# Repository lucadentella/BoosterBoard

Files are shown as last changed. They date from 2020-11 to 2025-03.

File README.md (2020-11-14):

# BoosterBoard
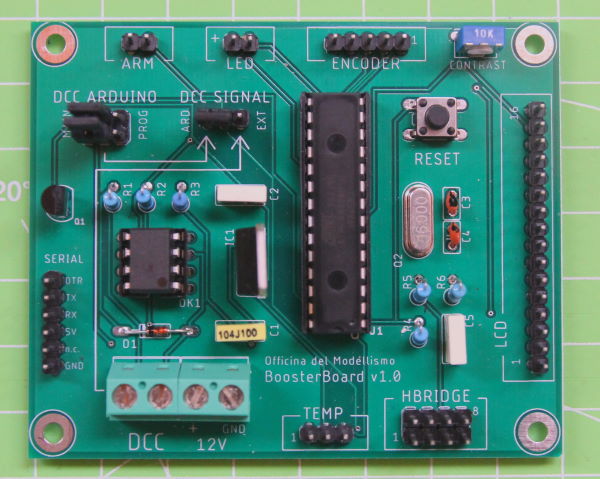
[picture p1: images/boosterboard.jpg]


BoosterBoard is an opensource board to create a powerful DCC Booster or Command Station.

*BoosterBoard è una scheda opensource disegnata per realizzare un potente Booster DCC o una completa Centralina Digitale.*

## Documentation
 - [Youtube video](https://www.youtube.com/watch?v=jXaGD2t4H4I)
 - [Assembly instructions (*english*)](https://github.com/lucadentella/BoosterBoard/blob/main/documentation/assembly-en.md)
 - [Guide for use as a DCC Booster (*english*)](https://github.com/lucadentella/BoosterBoard/blob/main/documentation/booster-en.md)
 - [Guide for use as a DCC Command Station (*english*)](https://github.com/lucadentella/BoosterBoard/blob/main/documentation/commandstation-en.md)
 
## Documentazione
 - [Video su Youtube](https://www.youtube.com/watch?v=6GtECbDPArw)
 - [Istruzioni per il montaggio (*italiano*)](https://github.com/lucadentella/BoosterBoard/blob/main/documentation/assembly-it.md)
 - [Guida per l'utilizzo come Booster DCC (*italiano*)](https://github.com/lucadentella/BoosterBoard/blob/main/documentation/booster-it.md)
 - [Guida per l'utilizzo come Centralina DCC (*italiano*)](https://github.com/lucadentella/BoosterBoard/blob/main/documentation/commandstation-it.md)

## Technical documents / *Documenti tecnici*
 - [Schematics / *Schema elettrico* (pdf)](https://github.com/lucadentella/BoosterBoard/blob/main/board/BoosterBoard.pdf)
 - [Eagle files](https://github.com/lucadentella/BoosterBoard/tree/main/board)
 - [Part list / *Elenco componenti*](https://github.com/lucadentella/BoosterBoard/blob/main/documentation/partlist.md)

## PCB
PCBs can be ordered directly from PCBWay
*I PCB possono essere ordinati direttamente da PCBWay* 
https://www.pcbway.com/project/shareproject/BoosterBoard.html

## References / *Riferimenti*
 - [A High Power DCC Booster](http://www.trainelectronics.com/DCC_Arduino/DCC_Booster/) (D. Bodnar)
 - [DCC++ BaseStation](https://github.com/DccPlusPlus/BaseStation)

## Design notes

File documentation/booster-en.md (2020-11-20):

# BoosterBoard as DCC Booster

## Firmware

Connect a USB to Serial adapter to the `SERIAL` port as follows:

> It's important to connect `DTR` pin to automatically reset the microcontroller during programing and to **swap** `RX` and `TX` pins

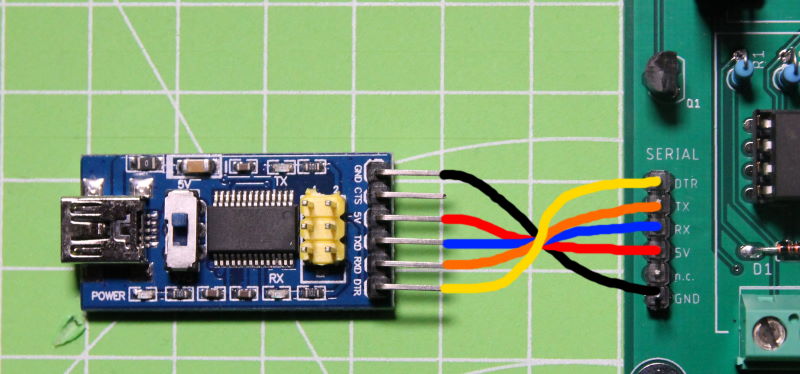
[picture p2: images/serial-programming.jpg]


Download the [latest firmware](https://github.com/lucadentella/BoosterBoard/tree/main/firmware) from Github and program using Arduino IDE (select *Arduino Uno* as board).

## Jumpers

Insert the jumpers as follows:

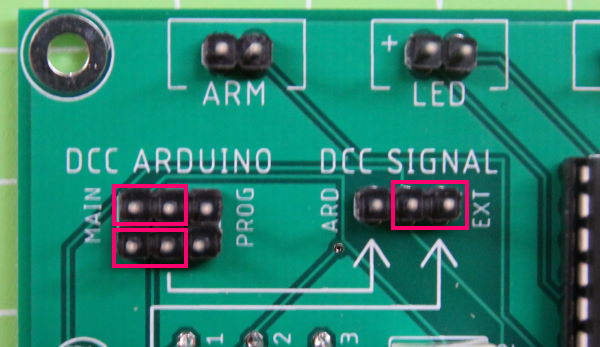
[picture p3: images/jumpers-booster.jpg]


## Connections

Connect LED, button and encoder as follows:

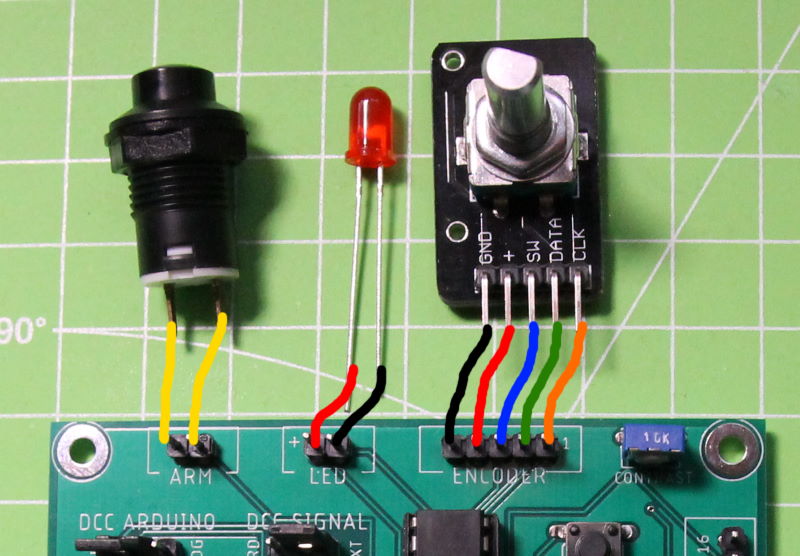
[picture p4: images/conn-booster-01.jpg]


Connect the display to the corresponding port (`LCD`), **pin to pin** (1->1, 2->2...): 

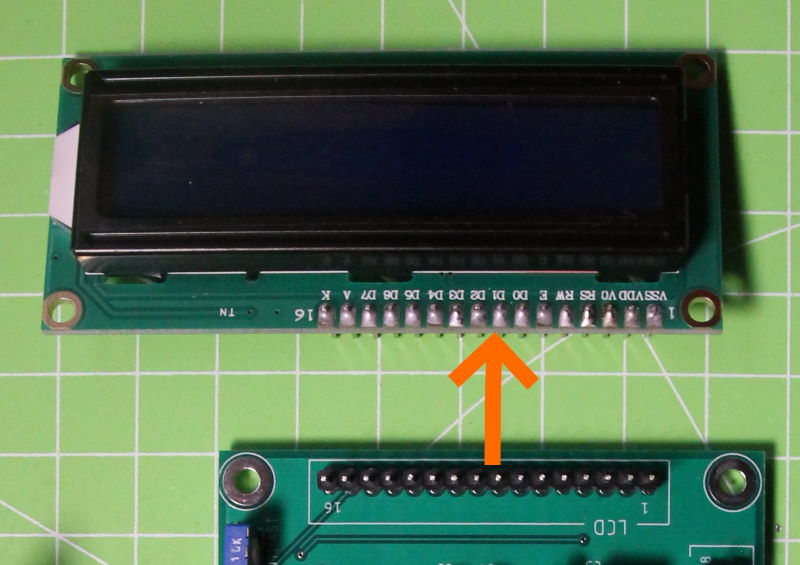
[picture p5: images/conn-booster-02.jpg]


Connect the H-Bridge board to `H-BRIDGE` port (1->1, 2->2...) and the temperature sensor as follows:

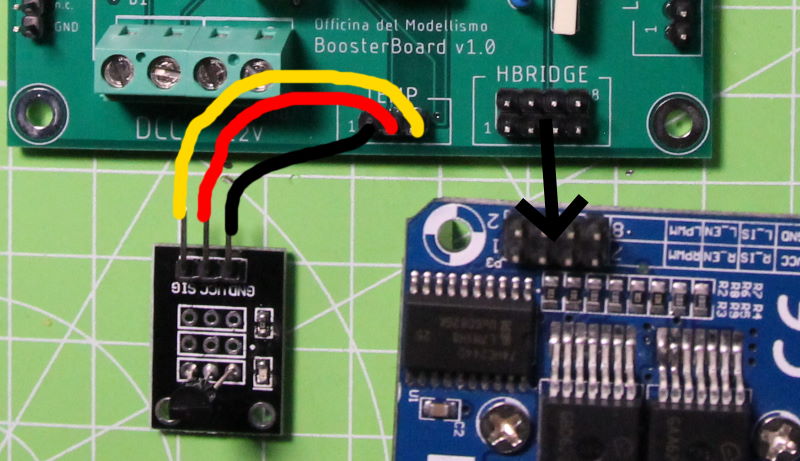
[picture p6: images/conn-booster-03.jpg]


## Operation

Power BoosterBoard connecting **12V and GND**. Connect the **DCC** input signal to the `DCC` terminal block.

Power the H bridge (`B+ B-` terminals) and connect the output (`M+ M-` terminals) to the layout:

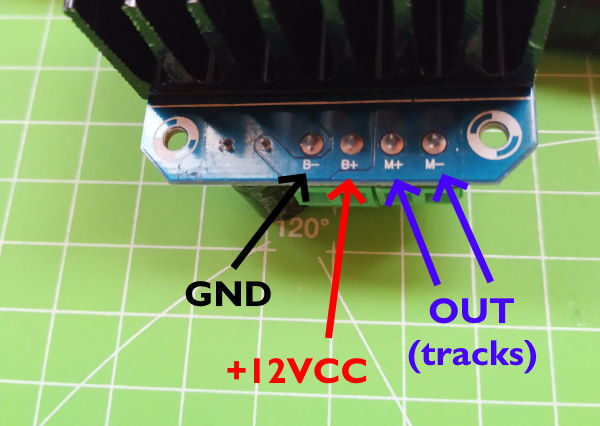
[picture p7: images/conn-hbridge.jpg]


BoosterBoard starts in **STOP** mode. You can turn the booster ON and OFF pressing the push button.

When the booster is OFF, you can change the maximum current and temperature using the rotary encoder.

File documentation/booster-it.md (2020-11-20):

# BoosterBoard come DCC Booster

## Firmware

Colleghiamo un adattatore USB Seriale alla porta `SERIAL` come segue:

> E' importante collegare il pin `DTR` per il reset automatico del microcontrollore durante la programmazione  e **invertire** i pin `RX` e `TX`



Scarichiamo [l'ultima versione del firmware](https://github.com/lucadentella/BoosterBoard/tree/main/firmware) da Github e programmiamo la scheda usando l'IDE di Arduino (selezioniamo *Arduino Uno* come scheda).

## Jumpers

Inseriamo i jumpers nelle posizioni evidenziate:



## Collegamenti

Colleghiamo il LED, il pulsante e l'encoder come segue:



Colleghiamo il display alla porta corrispondente (`LCD`), **pin to pin** (1->1, 2->2...): 



Colleghiamo il ponte H alla porta `H-BRIDGE` (1->1, 2->2...) e il sensore temperatura come segue:



## Funzionamento

Alimentiamo BoosterBoard collegando **12V e massa**. Colleghiamo il segnale **DCC** alla morsettiera `DCC`.

Alimentiamo il ponte H (morsettiera `B+ B-`) e colleghiamo la sua uscita (morsettiera `M+ M-`) al tracciato:



BoosterBoard si avvia in modalità **STOP**. E' possibile ACCENDERE e SPEGNERE il booster premendo il pulsante.

Quando il booster è SPENTO, è possibile modificare i valori massimi di corrente e temperatura usando l'encoder.

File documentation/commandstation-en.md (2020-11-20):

# BoosterBoard as DCC Command Station

## Firmware

Connect a USB to Serial adapter to the `SERIAL` port as follows:

> It's important to connect `DTR` pin to automatically reset the microcontroller during programing and to **swap** `RX` and `TX` pins



BoosterBoard is compatible with [DCC++ Base Station](https://github.com/DccPlusPlus/BaseStation). 

Download the latest version of this firmware from Github and program using Arduino IDE (select *Arduino Uno* as board).

## Jumpers

Insert the jumpers as follows:

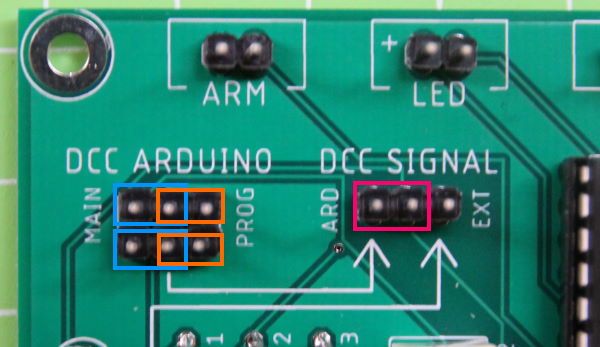
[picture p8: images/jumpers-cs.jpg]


Having only one H-Bridge, you have to choose which DCC++ signal will be its input.

Use the **blue** position for the `MAIN TRACK` signal or the **orange** position for the `PROGRAMMING TRACK` one.

## Connections

DCC++ doesn't support external peripherals like displays or buttons. 

You only need to connect a USB to Serial adapter to send commands to the command station from your computer. Connect the adapter as follows:

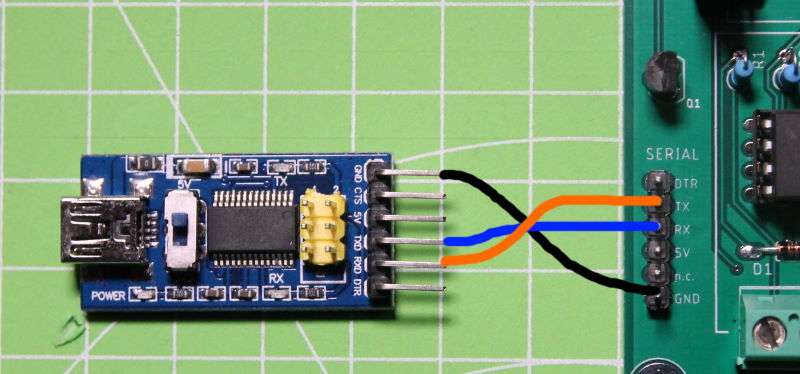
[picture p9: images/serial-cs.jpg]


## Operation

Power BoosterBoard connecting **12V and GND**.

Power the H bridge (`B+ B-` terminals) and connect the output (`M+ M-` terminals) to the layout:



Connect the Serial adapter to your computer.

Use a software which supports DCC++ to send commands to the command station and control your layout.

Some free programs I tested:

 - JMRI (https://www.jmri.org/)
 - Rocrail (https://wiki.rocrail.net/doku.php)

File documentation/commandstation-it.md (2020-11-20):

# BoosterBoard come Centralina DCC

## Firmware

Colleghiamo un adattatore USB Seriale alla porta `SERIAL` come segue:

> E' importante collegare il pin `DTR` per il reset automatico del microcontrollore durante la programmazione  e **invertire** i pin `RX` e `TX`



BoosterBoard è compatibile con [DCC++ Base Station](https://github.com/DccPlusPlus/BaseStation). 

Scarichiamo l'ultima versione del firmware da Github e programmiamo la scheda usando l'IDE di Arduino (selezioniamo *Arduino Uno* come scheda).

## Jumpers

Inseriamo i jumpers nelle posizioni evidenziate:



Avendo solo un ponte H, dobbiamo scegliere quale segnale DCC++ inviare al suo ingresso.

Usiamo le posizioni in **blu** per il `TRACCIATO PRINCIPALE (MAIN`) o le posizioni in **arancione** per il `BINARIO DI PROGRAMMAZIONE`.

## Collegamenti

DCC++ non supporta periferiche esterne come display o pulsanti. 

Dobbiamo solo collegare un adattatore USB Seriale per inviare comandi alla command station dal nostro computer. Colleghiamo l'adattatore come segue:



## Funzionamento

Alimentiamo BoosterBoard collegando **12V e massa**.

Alimentiamo il ponte H (morsettiera `B+ B-`) e colleghiamo la sua uscita (morsettiera `M+ M-`) al tracciato:



Colleghiamo l'adattatore seriale al nostro computer.

Utilizziamo un programma che supporti DCC++ per inviare comandi alla centralina e controllare il plastico.

Alcuni programmi gratuiti che ho testato:

 - JMRI (https://www.jmri.org/)
 - Rocrail (https://wiki.rocrail.net/doku.php)

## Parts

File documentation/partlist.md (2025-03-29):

# Part list / *Elenco componenti*
## For the board / Per la scheda
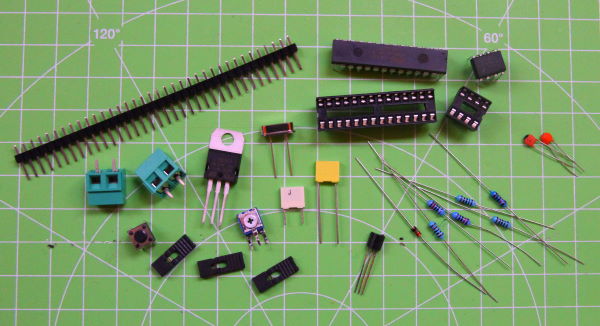
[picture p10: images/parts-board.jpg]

|Name|Description|Value
|--|--|--|
|R1,R6|Resistor 1/4W 1%|1Kohm|
|R2,R3,R4,R5|Resistor 1/4W 1%|10Kohm|
|R7|Variable resistor (RM063)|10Kohm|
|C1|Ceramic capacitor|330nF|
|C2,C5|Ceramic capacitor|100nF|
|C3,C4|Ceramic capacitor|22pF|
|D1|Diode|1N4148|
|Q1|Mosfet|2N7000|
|Q2|Crystal|16MHz|
|U1|Microcontroller|ATmega328p|
|OK1|Optocoupler|6N137|
|IC1|Voltage regulator|L7805|
|RESET_SW|Tactile switch|Omron|
|12VCC,DCC|Terminal block|2P 5mm|
|JMPs|Jumpers|
|ARM,DCC_IN,DCC_OUT...|Pin headers|
## To use as a DCC Booster / Per l'utilizzo come Booster DCC
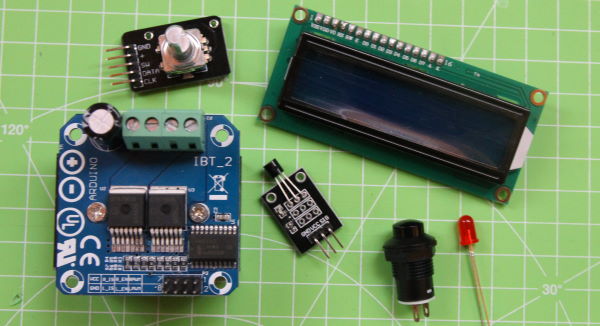
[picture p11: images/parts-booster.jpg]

> Links are for reference only, similar products will work well too / *I link sono forniti solo come riferimento, prodotti simili funzioneranno egualmente bene*

|Name|Description|Link
|--|--|--|
|HBRIDGE|BTS7960B motor driver / *Driver motori BTS7960B*|https://www.aliexpress.com/w/wholesale-double-BTS7960B.html|
|ARM|Momentary push button / *Pulsante da pannello*|https://bit.ly/2Idf11M|
|LED|LED, choose the color you prefer / *LED, scegli il colore che preferisci*|
|ENCODER|EC11 Rotary encoder / *Encoder rotativo*|https://www.aliexpress.com/w/wholesale-ec11-rotary-encoder.html
|LCD|16x2 character display / *Display a caratteri 16x2*|https://www.aliexpress.com/w/wholesale-lcd-16x2.html
|TEMP|DS18B20 temperature sensor / *Sensore temperatura DS18B20*|https://www.aliexpress.com/w/wholesale-DS18B20-module-single.html
## To use as a DCC Command Station / Per l'utilizzo come Centralina DCC
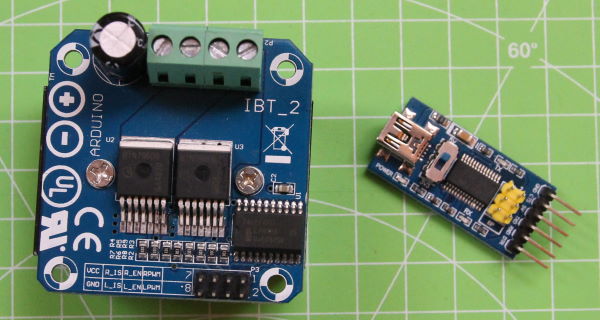
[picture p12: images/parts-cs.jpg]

|Name|Description|Link
|--|--|--|
|HBRIDGE|BTS7960B motor driver / *Driver motori BTS7960B*|https://www.aliexpress.com/w/wholesale-double-BTS7960B.html|
|SERIAL|USB to serial adapter / *Modulo USB - seriale*|https://www.aliexpress.com/w/wholesale-usb-serial-adapter.html

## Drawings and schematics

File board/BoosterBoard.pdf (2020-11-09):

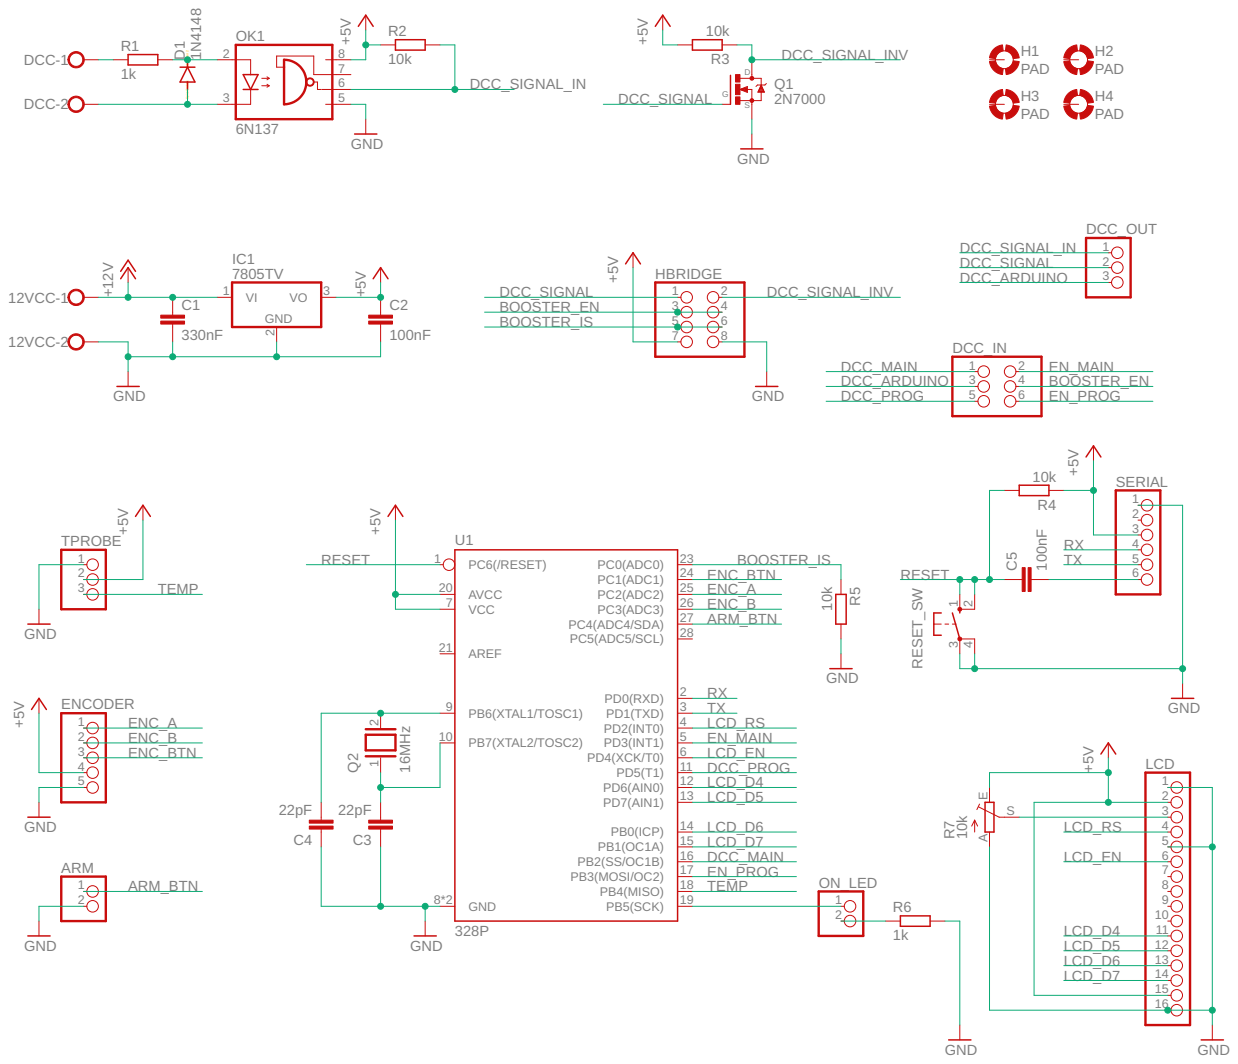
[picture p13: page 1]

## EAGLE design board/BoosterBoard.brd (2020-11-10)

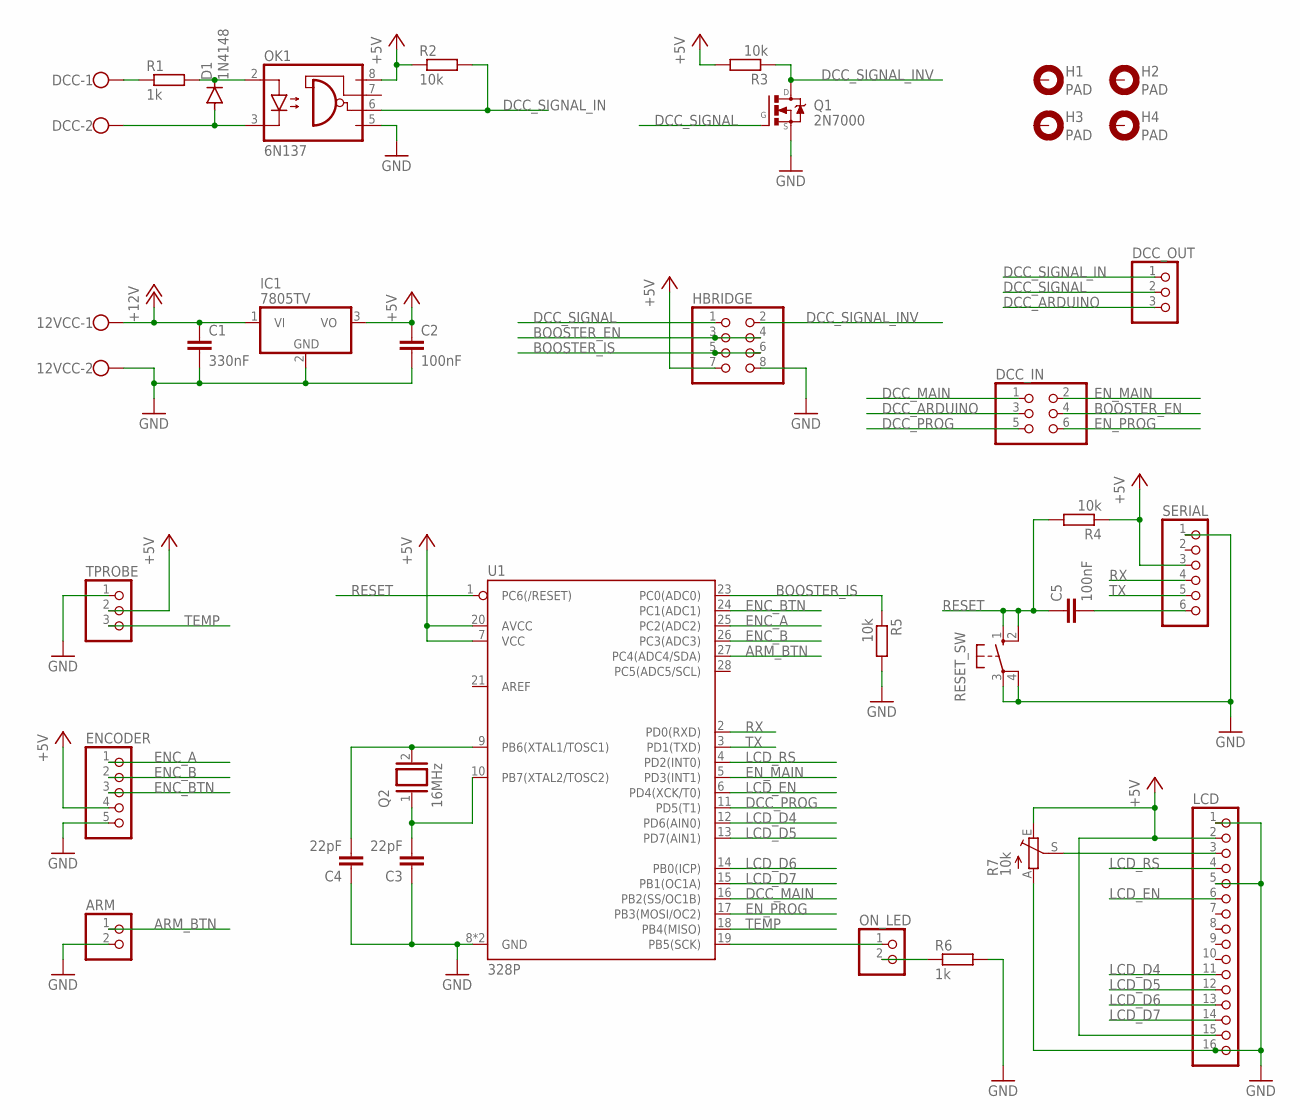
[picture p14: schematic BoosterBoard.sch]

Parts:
12VCC: W237-102
ARM: PINHD-1X2; 1X02
C1: 330nF; C050-030X075
C2, C5: 100nF; C050-030X075
C3, C4: 22pF; C025-025X050
D1: 1N4148; DO35-10
DCC: W237-102
DCC_IN: PINHD-2X3; 2X03
DCC_OUT: PINHD-1X3; 1X03
ENCODER: PINHD-1X5; 1X05
H1, H2, H3, H4: PAD; 3,0-PAD
HBRIDGE: PINHD-2X4; 2X04
IC1: 7805TV; TO220V
LCD: PINHD-1X16; 1X16
OK1: 6N137; DIL08
ON_LED: PINHD-1X2; 1X02
Q1: 2N7000; TO-92
Q2: 16MHz; QS
R1, R6: 1k; 0207/2V
R2, R3, R4, R5: 10k; 0207/2V
R7: 10k; B64W
RESET_SW: 10-XX; B3F-10XX
SERIAL: PINHD-1X6; 1X06
TPROBE: PINHD-1X3; 1X03
U1: 328P; DIP28

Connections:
+5V: C2.1, ENCODER.4, HBRIDGE.7, IC1.3 (VO), LCD.2, LCD.15, OK1.8 (VCC), R2.1, R3.2, R4.1, R7.E, SERIAL.3, TPROBE.2, U1.7 (VCC), U1.20 (AVCC)
+12V: 12VCC.1, C1.1, IC1.1 (VI)
ARM_BTN: ARM.1, U1.27 (PC4(ADC4/SDA))
BOOSTER_EN: DCC_IN.4, HBRIDGE.3, HBRIDGE.4
BOOSTER_IS: HBRIDGE.5, HBRIDGE.6, R5.1, U1.23 (PC0(ADC0))
DCC_ARDUINO: DCC_IN.3, DCC_OUT.3
DCC_MAIN: DCC_IN.1, U1.16 (PB2(SS/OC1B))
DCC_PROG: DCC_IN.5, U1.11 (PD5(T1))
DCC_SIGNAL: DCC_OUT.2, HBRIDGE.1, Q1.2 (G)
DCC_SIGNAL_IN: DCC_OUT.1, OK1.6 (VO), R2.2
DCC_SIGNAL_INV: HBRIDGE.2, Q1.3 (D), R3.1
ENC_A: ENCODER.1, U1.25 (PC2(ADC2))
ENC_B: ENCODER.2, U1.26 (PC3(ADC3))
ENC_BTN: ENCODER.3, U1.24 (PC1(ADC1))
EN_MAIN: DCC_IN.2, U1.5 (PD3(INT1))
EN_PROG: DCC_IN.6, U1.17 (PB3(MOSI/OC2))
GND: 12VCC.2, ARM.2, C1.2, C2.2, C3.1, C4.1, ENCODER.5, HBRIDGE.8, IC1.2 (GND), LCD.1, LCD.5, LCD.16, OK1.5 (GND), Q1.1 (S), R5.2, R6.2, R7.A, RESET_SW.3, RESET_SW.4 (P1), SERIAL.1, TPROBE.1, U1.8 (GND), U1.22 (GND)
LCD_D4: LCD.11, U1.12 (PD6(AIN0))
LCD_D5: LCD.12, U1.13 (PD7(AIN1))
LCD_D6: LCD.13, U1.14 (PB0(ICP))
LCD_D7: LCD.14, U1.15 (PB1(OC1A))
LCD_EN: LCD.6, U1.6 (PD4(XCK/T0))
LCD_RS: LCD.4, U1.4 (PD2(INT0))
unnamed: DCC.1, R1.1
unnamed: D1.C, OK1.2 (A), R1.2
unnamed: D1.A, DCC.2, OK1.3 (C)
unnamed: C4.2, Q2.2, U1.9 (PB6(XTAL1/TOSC1))
unnamed: C3.2, Q2.1, U1.10 (PB7(XTAL2/TOSC2))
unnamed: C5.2, SERIAL.6
unnamed: ON_LED.1, U1.19 (PB5(SCK))
unnamed: ON_LED.2, R6.1
unnamed: LCD.3, R7.S
RESET: C5.1, R4.2, RESET_SW.1 (S), RESET_SW.2 (S1), U1.1 (PC6(/RESET))
RX: SERIAL.4, U1.2 (PD0(RXD))
TEMP: TPROBE.3, U1.18 (PB4(MISO))
TX: SERIAL.5, U1.3 (PD1(TXD))

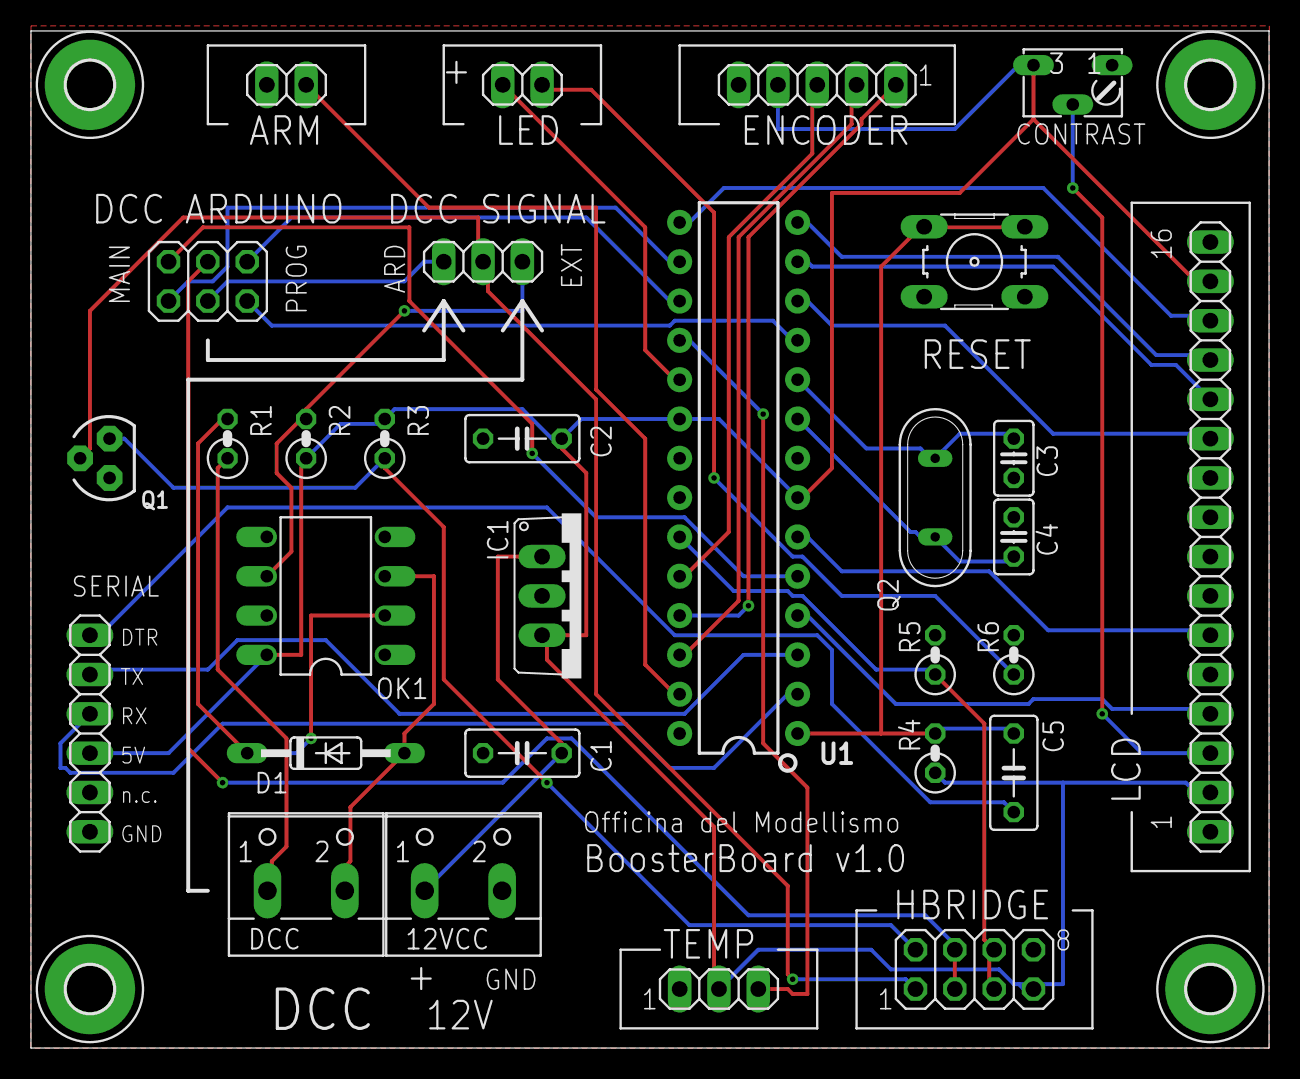
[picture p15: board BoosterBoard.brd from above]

Board: 2 copper layers, 80.0 x 65.7 mm, 34 parts (0 on the bottom side), 36 nets.

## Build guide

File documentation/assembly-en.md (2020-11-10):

# Assembly instructions
Start soldering the lowest components (diode, crystal, 22pf capacitors). I strongly suggest the use of **sockets** for ICs:

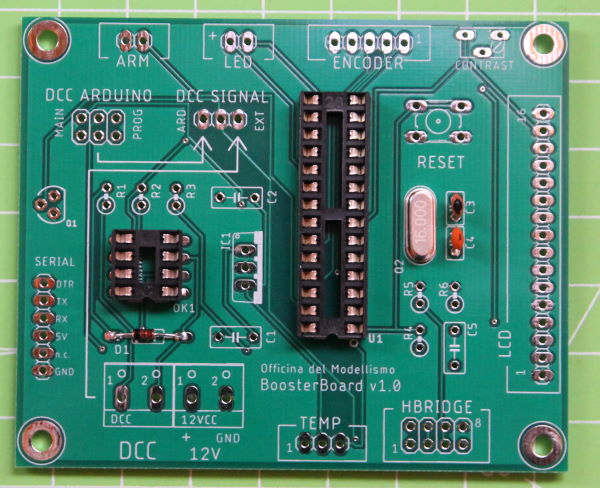
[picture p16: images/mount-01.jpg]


Continue with the remaining capacitors and the the transistor:

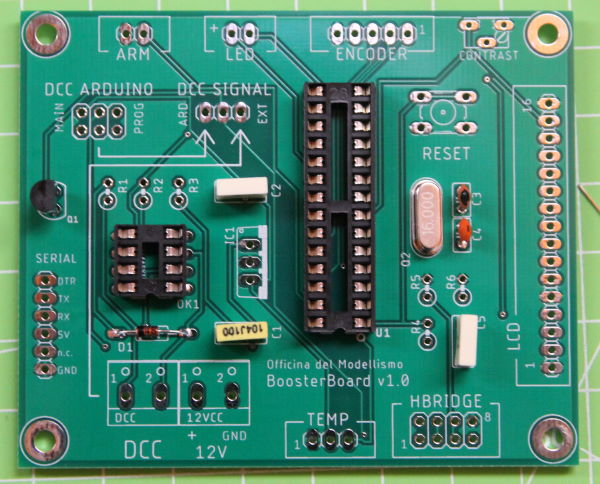
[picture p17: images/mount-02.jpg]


It's now time to solder the resistors (including the variable one), the pin headers and the switch:

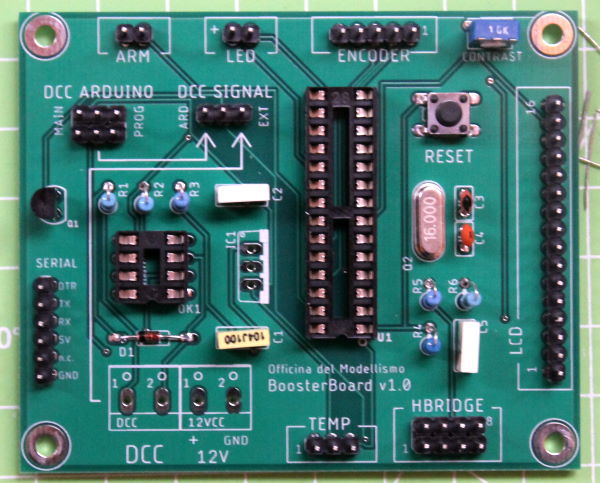
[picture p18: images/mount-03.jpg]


Complete the board with the terminal blocks and the voltage regulator:

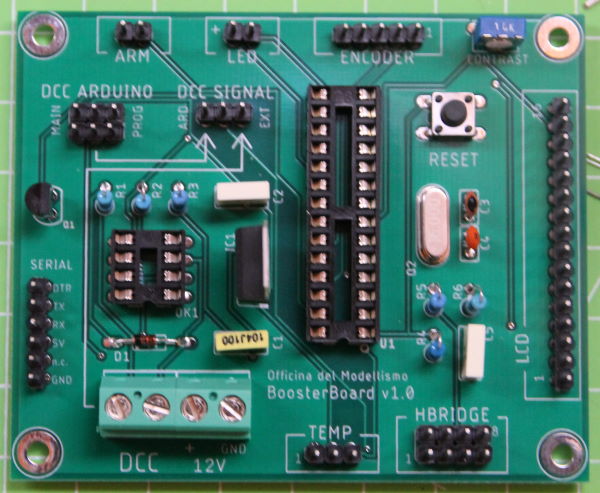
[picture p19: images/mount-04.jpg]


If you chose to use sockets, now you can insert the ICs. 
ATmega328p must be programmed with **Arduino bootloader**. You can buy pre-programmed microcontrollers or burn the bootloader using one Arduino Uno running the *ArduinoISP* firmware:



I found very useful [this shield](https://bit.ly/38shwaZ) to program the bootloader:

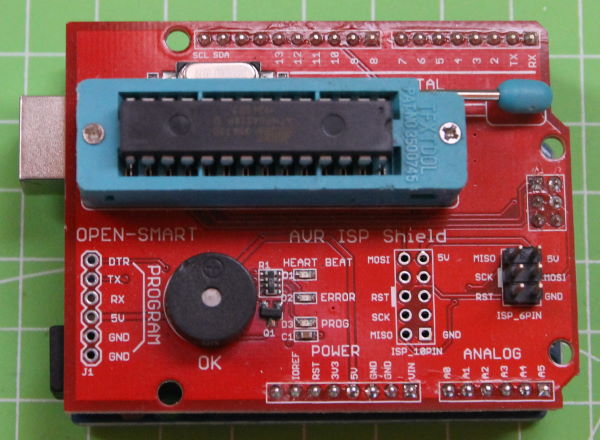
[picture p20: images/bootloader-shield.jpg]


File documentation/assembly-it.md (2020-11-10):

# Istruzioni per il montaggio
Iniziamo saldando i componenti più bassi (diodo, quarzo, condensatori da 22pf). Consiglio fortemente l'utilizzo di **sockets** per i circuiti integrati:



Continuiamo con i condensatori rimanenti e il transistor:



E' ora tempo di saldare le resistenze (inclusa quella variabile), i pin e il pulsante:



Completiamo la scheda con le morsettiere e il regolatore di tensione:



Se avete scelto di usare i sockets, è ora possibile inserire i circuiti stampati. 
L'atmega328p deve essere programmato con il **bootloader Arduino**. E' possibile acquistare microcontrollori già programmati o programmare il bootloader usando un Arduino Uno che esegue il firmware *ArduinoISP*:



Ho trovato molto utile [questo shield](https://bit.ly/38shwaZ) per programmare il bootloader:



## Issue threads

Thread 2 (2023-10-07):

Shortcircuit is to fast

Knitterpitti, 2023-10-07:
Hello Luca,
at first i will thank you for this great Project.

I have build the Boosterboard it runs fine with a DCC++ Arduino Central and Rocrail.
But i use two sweeping loop´s with DR 5013 Modules.
[https://www.manualslib.com/manual/1512127/Digikeijs-Dr5013-Digireverse.html#manual](url)
Now my Problem:
The Shortcircuit detection from the booster is faster then the Modules can switch the Polarisation.

Can you insert a delay witch stop the Booster after a half Second after the short circuit!
Not directly after detection!

My Central Station DR5000 is going to shortcircuit after 100 miliseconds this runs great with the sweeping loop´s.

Thank you for your Time,

Greatings Sebastian Kuhnert (Knitterpitti)

lucadentella, 2023-10-09:
Hi Sebastian

I'm not going to change the normal behavior of the booster because it's important to detect a short circuit as soon as it happens.

Anyway I'm aware that some loop modules do require some ms to activate.
You can alter the code that detects short circuits, starting from line:

https://github.com/lucadentella/BoosterBoard/blob/06c8bd1694cb7f5fff553e723a42c103eaa35553/firmware/BoosterBoard-10.ino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

at the moment I get only one sample and if it's greater than 1000, activate the short circuit protection. You can add here a delay and check again: only if after 100-200ms the read value is still high, trigger the protection.

Let me know if it works, I won't include it in the "main" source code because I think that most of the users will prefer a fast protection if they don't use any loop modules.

Knitterpitti, 2023-10-09:
Hello Luca,
okay so i will try it.
i create a new line after 124
and wrote / delay(300)

lucadentella, 2023-10-22:
you should check after 200-300ms the value:

int sample = analogRead(BOOSTER_CURRENT_PIN);
  if(sample > 1000) {
  delay(200);
sample = analogRead(BOOSTER_CURRENT_PIN);
  if(sample > 1000) {
    currentWorkingMode = W_ALERT_SHORT;
    boosterOff();
    Serial.println("Booster OFF due to a short circuit");
    return;
  }

Closed 2023-10-22.

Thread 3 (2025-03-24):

Link aggiornati componenti

ottopic, 2025-03-24:
E' possibile avere i link aggiornati dei componenti? Su banggood non riesco a trovare un sensore di temperatura corretto e un encoder rotativo

Grazie

lucadentella, 2025-03-29:
Aggiornati, purtroppo banggood non è più un'ottima fonte di componenti elettronici, ho messo i link ad aliexpress

Closed 2025-03-29.

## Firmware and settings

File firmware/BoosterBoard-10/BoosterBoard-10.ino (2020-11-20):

#include <EEPROM.h>
#include <OneWire.h>
#include <DallasTemperature.h>
#include <RotaryEncoder.h>
#include <LiquidCrystal.h>

#include "BoosterBoard.h"

OneWire oneWire(TEMPERATURE_PIN);
DallasTemperature sensors(&oneWire);
RotaryEncoder encoder(ENCODER_PIN_A, ENCODER_PIN_B);
LiquidCrystal lcd(LCD_RS, LCD_EN, LCD_D4, LCD_D5, LCD_D6, LCD_D7);

// Current and temperature values
float current;
float maxCurrent = 5.0;
float temperature;
float maxTemperature = 60.0;

// Current and temperature sampling
int currentSampleCount = 0;
long currentSampleSum = 0;
bool temperatureRequested = false;
long temperatureRequestTime = 0;

// FSM
int currentWorkingMode;
int currentConfigStatus;

// Encoder
int encoderPosition = 0;
bool currentChoice = true;

// Buttons
bool armButtonAlreadyPressed = false;
bool encButtonAlreadyPressed = false;
bool armButtonDebounce = false;
bool encButtonDebounce = false;
long armButtonDebounceTime = 0;
long encButtonDebounceTime = 0;


void setup() {

  Serial.begin(115200);
  Serial.print("BoosterBoard v");
  Serial.println(FIRMWARE_VERSION);
  Serial.println();
  
  pinMode(BOOSTER_ENABLE_PIN, OUTPUT);
  pinMode(STATUS_LED_PIN, OUTPUT);
  pinMode(ENCODER_PIN_BTN, INPUT_PULLUP);
  pinMode(ARM_PIN_BTN, INPUT_PULLUP);  
  Serial.println("PIN setup complete");

  currentWorkingMode = W_STOP;
  boosterOff();
  Serial.println("Booster OFF at startup");

  // read values from EEPROM if valid, else store default values
  byte eepromValid;
  EEPROM.get(E_VALID_VALUES, eepromValid);
  if(eepromValid == 123) {
    EEPROM.get(E_MAX_CURR_ADDR, maxCurrent);
    EEPROM.get(E_MAX_TEMP_ADDR, maxTemperature);
    Serial.println("Max values retrieved from EEPROM");
  } else {
    eepromValid = 123;
    EEPROM.put(E_MAX_CURR_ADDR, maxCurrent);
    EEPROM.put(E_MAX_TEMP_ADDR, maxTemperature);
    EEPROM.put(E_VALID_VALUES, eepromValid);
    Serial.println("Default values stored in EEPROM");
  }

  sensors.begin();
  sensors.setWaitForConversion(false);
  Serial.println("Temperature sensor initialized");

  lcd.begin(16, 2);
  lcd.createChar(0, selectChar);
  lcd.createChar(1, modifyChar);  
  Serial.println("LCD initialized");
  lcd.setCursor(2, 0);
  lcd.print("BoosterBoard");
  lcd.setCursor(6, 1);
  lcd.print("v");
  lcd.print(FIRMWARE_VERSION);
  
  delay(2000);
  lcd.clear();
  printLCDFirstLine();
  printLCDSecondLine();
  printMaxCurrent();
  printMaxTemperature();
  printCursor();
  Serial.println();
  Serial.println("Booster ready!");
  Serial.println();
}

void loop() {

  // if working, check temperature and current
  if(currentWorkingMode == W_POWER) {
    checkCurrent(); 
    checkTemperature();
  }

  // if not working, check encoder and its button
  else {

    encoder.tick();
    checkEncoder();
    checkEncButton();
  }

  // always check the ARM button
  checkARMbutton();
}

void checkCurrent() {

  int sample = analogRead(BOOSTER_CURRENT_PIN);
  if(sample > 1000) {
    currentWorkingMode = W_ALERT_SHORT;
    boosterOff();
    Serial.println("Booster OFF due to a short circuit"); 
    return;
  }
  currentSampleSum += sample;
  currentSampleCount++;

  if(currentSampleCount == CURRENT_SAMPLES) {
    float newCurrent = 0.00415 * (currentSampleSum / CURRENT_SAMPLES);    
    if(newCurrent > maxCurrent) {
      currentWorkingMode = W_ALERT_CUR;
      boosterOff();
      current = newCurrent;
      printCurrent();
      Serial.println("Booster OFF due to max current reached");       
    }
    else if(current != newCurrent) {
      current = newCurrent;
      printCurrent();
    }
    currentSampleSum = 0;
    currentSampleCount = 0;
  }
}

void checkTemperature() {

  if(!temperatureRequested) {
    
    sensors.requestTemperatures();
    temperatureRequested = true;
    temperatureRequestTime = millis();
  } else {

    if(millis() > temperatureRequestTime + TEMPERATURE_WAIT_TIME) {

      float newTemperature = sensors.getTempCByIndex(0);
      if(newTemperature != DEVICE_DISCONNECTED_C) {

        if(newTemperature > maxTemperature) {
          currentWorkingMode = W_ALERT_TEMP;
          boosterOff();
          temperature = newTemperature;
          printTemperature(); 
          Serial.println("Booster OFF due to max temperture reached");                               
        }
        else if(temperature != newTemperature) {
          temperature = newTemperature;
          printTemperature();          
        }       
      }
      temperatureRequested = false;
    }    
  }
}

void checkARMbutton() {

  int armButtonStatus = digitalRead(ARM_PIN_BTN);
  
  // button pressed
  if(armButtonStatus == 0) {

    // already pressed? no further action
    if(armButtonAlreadyPressed) return;

    // do we need to debounce? 
    if(!armButtonDebounce) {
      armButtonDebounce = true;
      armButtonDebounceTime = millis();
      return;
    }

    // in debounce, if time has passed do the requested action
    else if(millis() > armButtonDebounceTime + DEBOUNCE_INTERVAL) {
      if(currentWorkingMode == W_POWER) {
        currentWorkingMode = W_STOP; 
        boosterOff();
        Serial.println("Booster OFF via ARM button");           
      }
      else {
        boosterOn();
        Serial.println("Booster ON via ARM button");
      }
      armButtonAlreadyPressed = true;
    }
  }

  // button not pressed, reset variables
  else {
    armButtonAlreadyPressed = false;
    armButtonDebounce = false;
  }  
}


void checkEncoder() {

  int newEncoderPosition = encoder.getPosition();
  if (encoderPosition != newEncoderPosition) {

    bool positiveIncrement = (encoderPosition > newEncoderPosition);
    
    switch(currentConfigStatus) {

      case S_SELECT:
        currentChoice = !currentChoice;
        printCursor();
        break;

      case S_MODIFY:
        bool changed = false;
        if(currentChoice) {
          if(positiveIncrement && maxCurrent < MAX_CURRENT) { maxCurrent += 0.1; changed = true; }
          if(!positiveIncrement && maxCurrent > 0.1) { maxCurrent -= 0.1; changed = true; }
          if(changed) {
            EEPROM.put(E_MAX_CURR_ADDR, maxCurrent);
            printMaxCurrent();
          } 
        }
        if(!currentChoice) {
          if(positiveIncrement && maxTemperature < MAX_TEMPERATURE) { maxTemperature += 1.0; changed = true; }
          if(!positiveIncrement && maxTemperature > 0.1) { maxTemperature -= 1.0; changed = true; }
          if(changed) {
            EEPROM.put(E_MAX_TEMP_ADDR, maxTemperature);
            printMaxTemperature();
          } 
        }      
        break; 
    }
    encoderPosition = newEncoderPosition;
  }
}

void checkEncButton() {

  int encButtonStatus = digitalRead(ENCODER_PIN_BTN);
  
  // button pressed
  if(encButtonStatus == 0) {

    // already pressed? no further action
    if(encButtonAlreadyPressed) return;

    // do we need to debounce? 
    if(!encButtonDebounce) {
      encButtonDebounce = true;
      encButtonDebounceTime = millis();
      return;
    }

    // in debounce, if time has passed do the requested action
    else if(millis() > encButtonDebounceTime + DEBOUNCE_INTERVAL) {
      if(currentConfigStatus == S_SELECT) currentConfigStatus = S_MODIFY;
      else currentConfigStatus = S_SELECT;
      printCursor();
      encButtonAlreadyPressed = true;      
    }
  }

  // button not pressed, reset variables
  else {
    encButtonAlreadyPressed = false;
    encButtonDebounce = false;
  }
}

void boosterOn() {

  digitalWrite(BOOSTER_ENABLE_PIN, HIGH);
  digitalWrite(STATUS_LED_PIN, HIGH);
  currentWorkingMode = W_POWER;
  currentConfigStatus = S_IDLE;
  current = -1.0;
  temperature = -1.0;  
  printLCDFirstLine();
  clearCursor();  
}

void boosterOff() {

  digitalWrite(BOOSTER_ENABLE_PIN, LOW);
  digitalWrite(STATUS_LED_PIN, LOW);
  currentConfigStatus = S_SELECT;
  printLCDFirstLine();
  printCursor();
}

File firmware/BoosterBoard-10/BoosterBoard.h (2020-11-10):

#define FIRMWARE_VERSION  "1.0"

// Hardware connections
#define BOOSTER_ENABLE_PIN  3
#define BOOSTER_CURRENT_PIN A0
#define ENCODER_PIN_A       A2
#define ENCODER_PIN_B       A3
#define ENCODER_PIN_BTN     A1
#define ARM_PIN_BTN         A4
#define TEMPERATURE_PIN     12
#define STATUS_LED_PIN      13
#define LCD_RS              2
#define LCD_EN              4
#define LCD_D4              6
#define LCD_D5              7
#define LCD_D6              8
#define LCD_D7              9

// EEPROM addresses
#define E_MAX_CURR_ADDR     0
#define E_MAX_TEMP_ADDR     10
#define E_VALID_VALUES      20

// Absolute maximum values
#define MAX_CURRENT         10.0
#define MAX_TEMPERATURE     80.0

// Sampling parameters
#define CURRENT_SAMPLES       4000
#define TEMPERATURE_WAIT_TIME 1000
#define DEBOUNCE_INTERVAL     50

// FSM
#define W_STOP              0
#define W_POWER             1
#define W_ALERT_CUR         2
#define W_ALERT_TEMP        3
#define W_ALERT_SHORT       4
#define S_IDLE              0
#define S_SELECT            1
#define S_MODIFY            2

// LCD custom chars
byte selectChar[] = {B00000,B00100,B00110,B11111,B00110,B00100,B00000,B00000};
byte modifyChar[] = {B00100,B01110,B11111,B00000,B11111,B01110,B00100,B00000};

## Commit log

2020-11-09 Schematic in PDF added
2020-11-10 Assembly instructions added
2020-11-10 PCBWay link added
2020-11-10 Eagle files added
    [BoosterBoard.brd, BoosterBoard.sch]
2020-11-20 Max current and temperature values fixed
    [BoosterBoard-10.ino]

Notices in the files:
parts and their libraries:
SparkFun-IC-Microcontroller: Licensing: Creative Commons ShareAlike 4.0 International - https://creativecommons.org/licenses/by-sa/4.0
